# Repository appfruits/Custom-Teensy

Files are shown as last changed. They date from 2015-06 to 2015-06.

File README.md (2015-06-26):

# Custom-Teensy
This is a reference pcb and schematics for a custom Teensy 3.1 board in EAGLE CAD format. More info on this can be found in our blog post at: http://www.appfruits.com/2015/03/building-your-own-custom-teensy/

#Wiki
Please post an issue if you have trouble or questions on the design. I will add new interesting things that I found in the issues and other sources (like PJRCs official forum or from eMail conversations) to the Wiki of this project. You are kindly invited to add things, too.
https://github.com/appfruits/Custom-Teensy/wiki

## License
<br /><span xmlns:dct="http://purl.org/dc/terms/" property="dct:title">Custom Teensy 3.1</span> von <a xmlns:cc="http://creativecommons.org/ns#" href="http://www.appfruits.com/2015/03/building-your-own-custom-teensy/" property="cc:attributionName" rel="cc:attributionURL">Phillip Schuster (Appfruits)</a> ist lizenziert unter einer <a rel="license" href="http://creativecommons.org/licenses/by-sa/4.0/">Creative Commons Namensnennung - Weitergabe unter gleichen Bedingungen 4.0 International Lizenz</a>.<br />Beruht auf dem Werk unter <a xmlns:dct="http://purl.org/dc/terms/" href="https://www.pjrc.com/store/teensy31.html" rel="dct:source">https://www.pjrc.com/store/teensy31.html</a>.

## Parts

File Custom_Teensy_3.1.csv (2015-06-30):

Qty | Value | Device | Package | Parts | Description | MF | MPN | OC_FARNELL | OC_NEWARK | PROD_ID | VALUE
1 |  | LED-GREEN | LED-0603 | LED1 | LEDs | Avago | HSMG-C190
10 | 0.1uF | CAPACITOR-0.1UF | 0603-CAP | C2, C4, C5, C11, C14, C16, C18, C19, C21, C22 |  | Kemet | C0603C104J3RACTU |  |  |  | 0.1uF
1 | 1.2M | RESISTOR-1.2M | 0603-RES | R7 | Resistor | Panasonic | ERJ-3GEYJ125V |  |  |  | 1.2M
1 | 10K | RESISTOR-10K | 0603-RES | R2 | Resistor | Panasonic | ERJ-3GEYJ103V |  |  |  | 10K
1 | 10uF | CAPACITOR-10UF | 0603-CAP | C1 |  | Murata | GRM188R60J106ME47D |  |  |  | 10uF
1 | 16Mhz/8pF | CRYSTAL/SMD-5X3-GND16MHZ/8PF | CRYSTAL-SMD-5X3 | Y2 |  | ECS | ECS-160-8-30B-CKM |  |  |  | 16Mhz/8pF
1 | 1981584-1 | 1981584-1 | 1981584-1 | J1 | Receptacle, micro-USB, type A/B | Hirose | ZX62-AB-5PA(11)
1 | 1K | RESISTOR-1K | 0603-RES | R10 | Resistor | Panasonic | ERJ-3GEYJ102V |  |  |  | 1K
2 | 2.2uF | CAPACITOR-2.2UF | 0603-CAP | C17, C20 |  | Kemet | C0603C225K4PACTU |  |  |  | 2.2uF
1 | 2.2uH, 2.1A | LPS30152.2UH | LPS3015 | L1 | Shielded Power Inductor | Coilcraft | LPS3015-222MRB |  |  |  | 2.2uH, 2.1A
2 | 220K | RESISTOR-220K | 0603-RES | R4, R6 | Resistor | Panasonic | ERJ-3GEYJ224V |  |  |  | 220K
1 | 22uF | CAPACITOR-22UF | 0603-CAP | C3 |  | Murata | GRM188R60J226MEA0D |  |  |  | 22uF
1 | 2M | RESISTOR-2M | 0603-RES | R3 | Resistor | Panasonic | ERJ-3GEYJ205V |  |  |  | 2M
1 | 32.768KHz | CRYSTAL/32.768KHZ/SMD-TXC_7A | CRYSTAL-TXC-7A | Y1 |  | Epson Timing | FC-255 32.7680K-A3
1 | 33 | 2R-NEXB34V | EXB34V | RN1 | Array Chip Resistor | Panasonic | EXB-34V330JV | unknown | unknown
3 | 470 | RESISTOR-470 | 0603-RES | R9, R16, R30 | Resistor | Panasonic | ERJ-3GEYJ471V |  |  |  | 470
3 | 600 Ohm/100 Mhz | INDUCTOR-BK2125HM601-T | 0805 | L2, L3, L4 | Inductors | Taiyo Yuden | BK2125HM601-T |  |  |  | 600 Ohm/100 Mhz
1 | AMBER/ 592 nm | LED-AMBER | LED-0603 | LED | LEDs | Avago Technologies | HSMA-C190 |  |  |  | AMBER/ 592 nm
1 | MINI54TAN | MINI54TAN | MINI54TAN | U3 | MINI54TAN Bootloader from PJRC.com, preprogrammed with Teensy 3.0 bootloader.
1 | MK20DX256VLH7 | MK20DX256VLH7 | MK20DX256VLH7 | U1 |  | Freescale | MK20DX256VLH7
1 | Program | SWITCH-MOMENTARY-2-SMD-1101NE | TACTILE-SWITCH-1101NE | PROGRAM | Various NO switches- pushbuttons, reed, etc | C&K Components | RS-282G05A3-SM RT
1 | TPS61200 | TPS61200 | QFN-10_PAD | U2 | DC to DC Booster | Texas Instruments | TPS61200DRCR |  |  | IC-10035

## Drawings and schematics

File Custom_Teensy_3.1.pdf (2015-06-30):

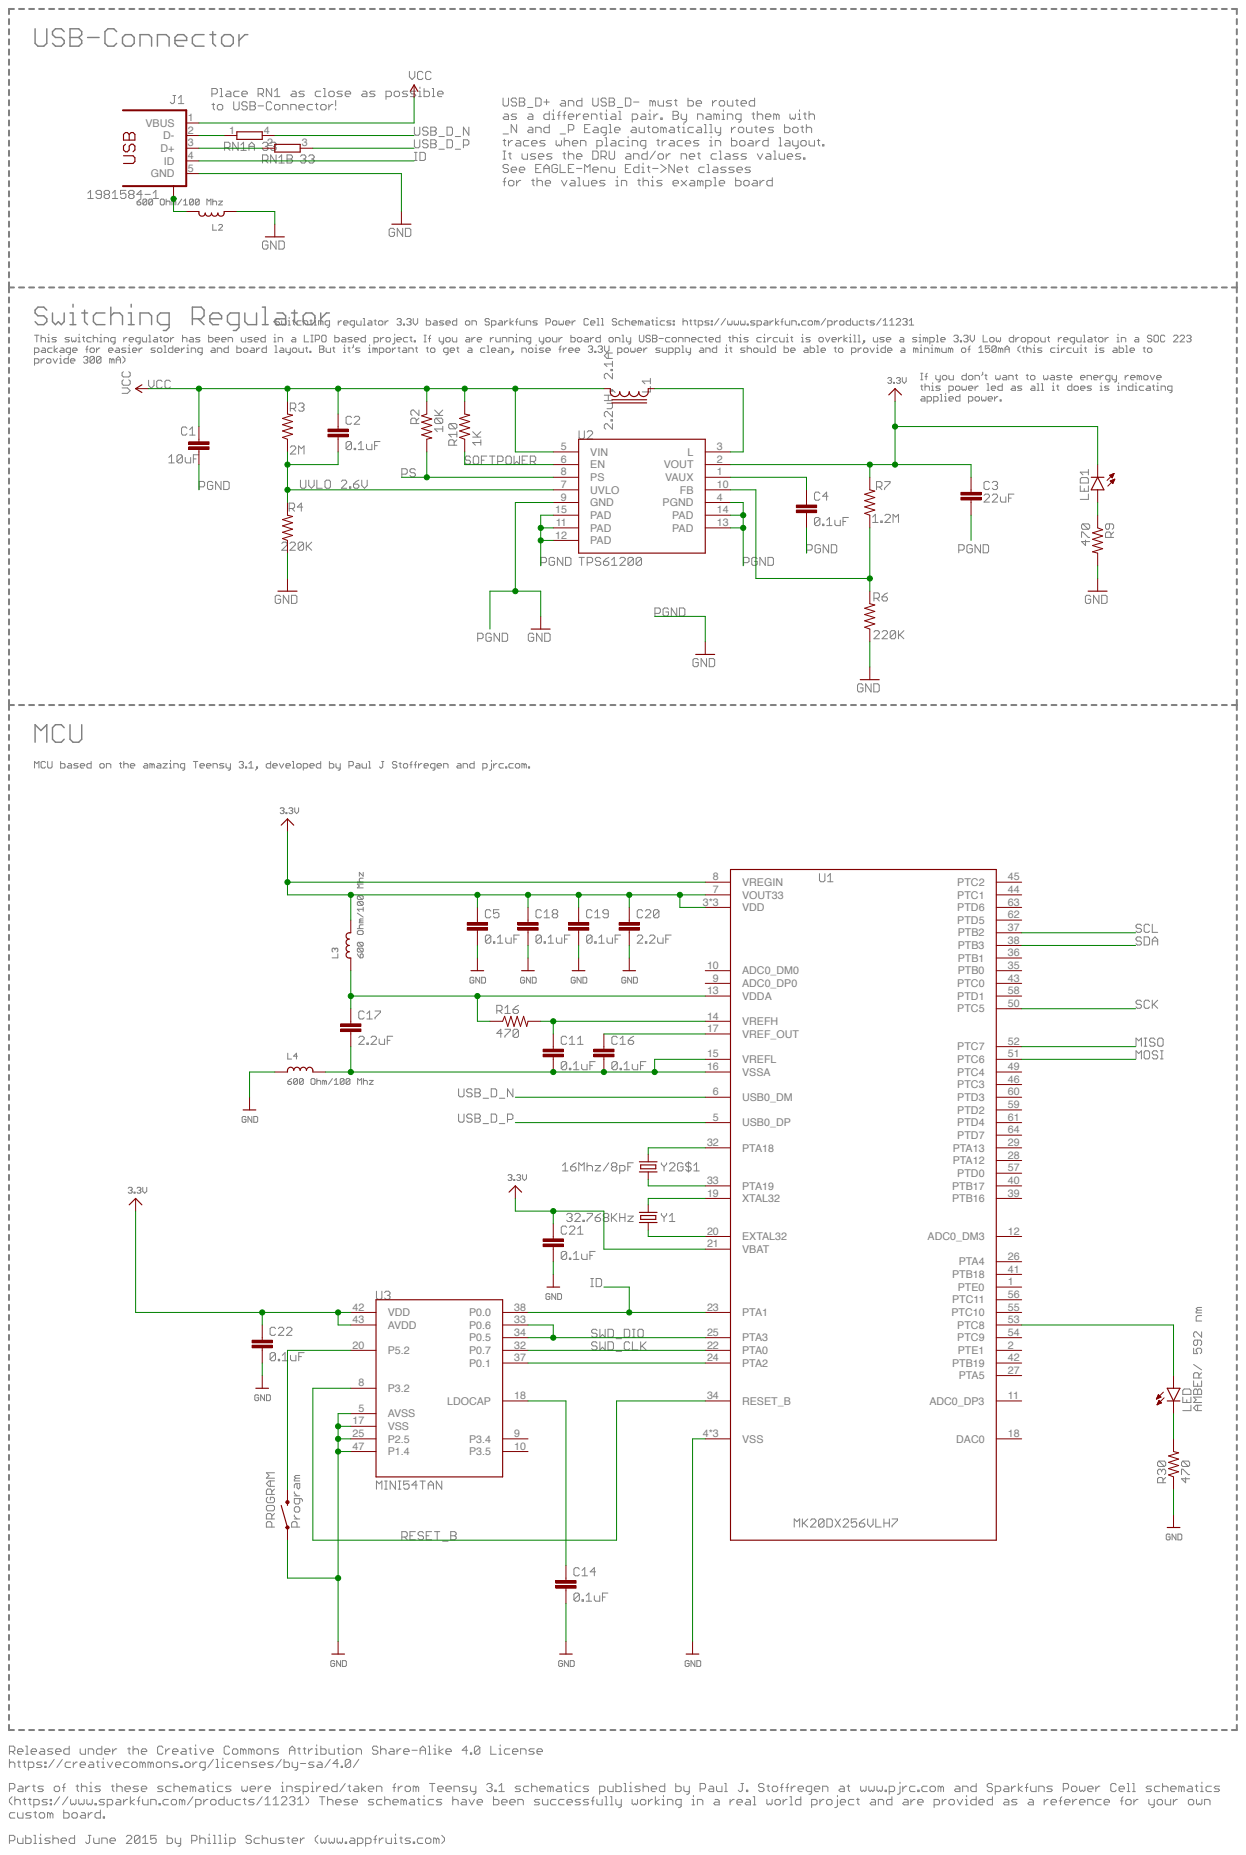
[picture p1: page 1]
GND; PAD 15 PAD 11; PAD 12; PAD; 13 PAD; 14 PGND; UVLO; VAUX; VIN; VOUT; VDD 42; VSS 17; AVDD 43; AVSS; LDOCAP; VREGIN; VOUT33; 7 VDD 3*3; ADC0_DM0 10; ADC0_DP0; 9 VDDA 13; VREFH 14 VREF_OUT 17; VREFL 15 VSSA 16; USB0_DM; USB0_DP; PTA18 32; PTC2; PTC1; PTD6; PTD5; PTB2; PTB3; PTB1; PTB0; PTD1; 58 PTC0; PTC5; PTC7; PTC6; PTC4; PTC3; PTD3; PTD2; PTD4; PTD7; PTA13; PTA12; PTD0; PTB17; PTB16; ADC0_DM3; PTA4; PTB18; PTE0; PTC11; PTC10; PTC8; PTC9; PTE1; PTB19; PTA5; ADC0_DP3; PTA19 33 XTAL32 19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

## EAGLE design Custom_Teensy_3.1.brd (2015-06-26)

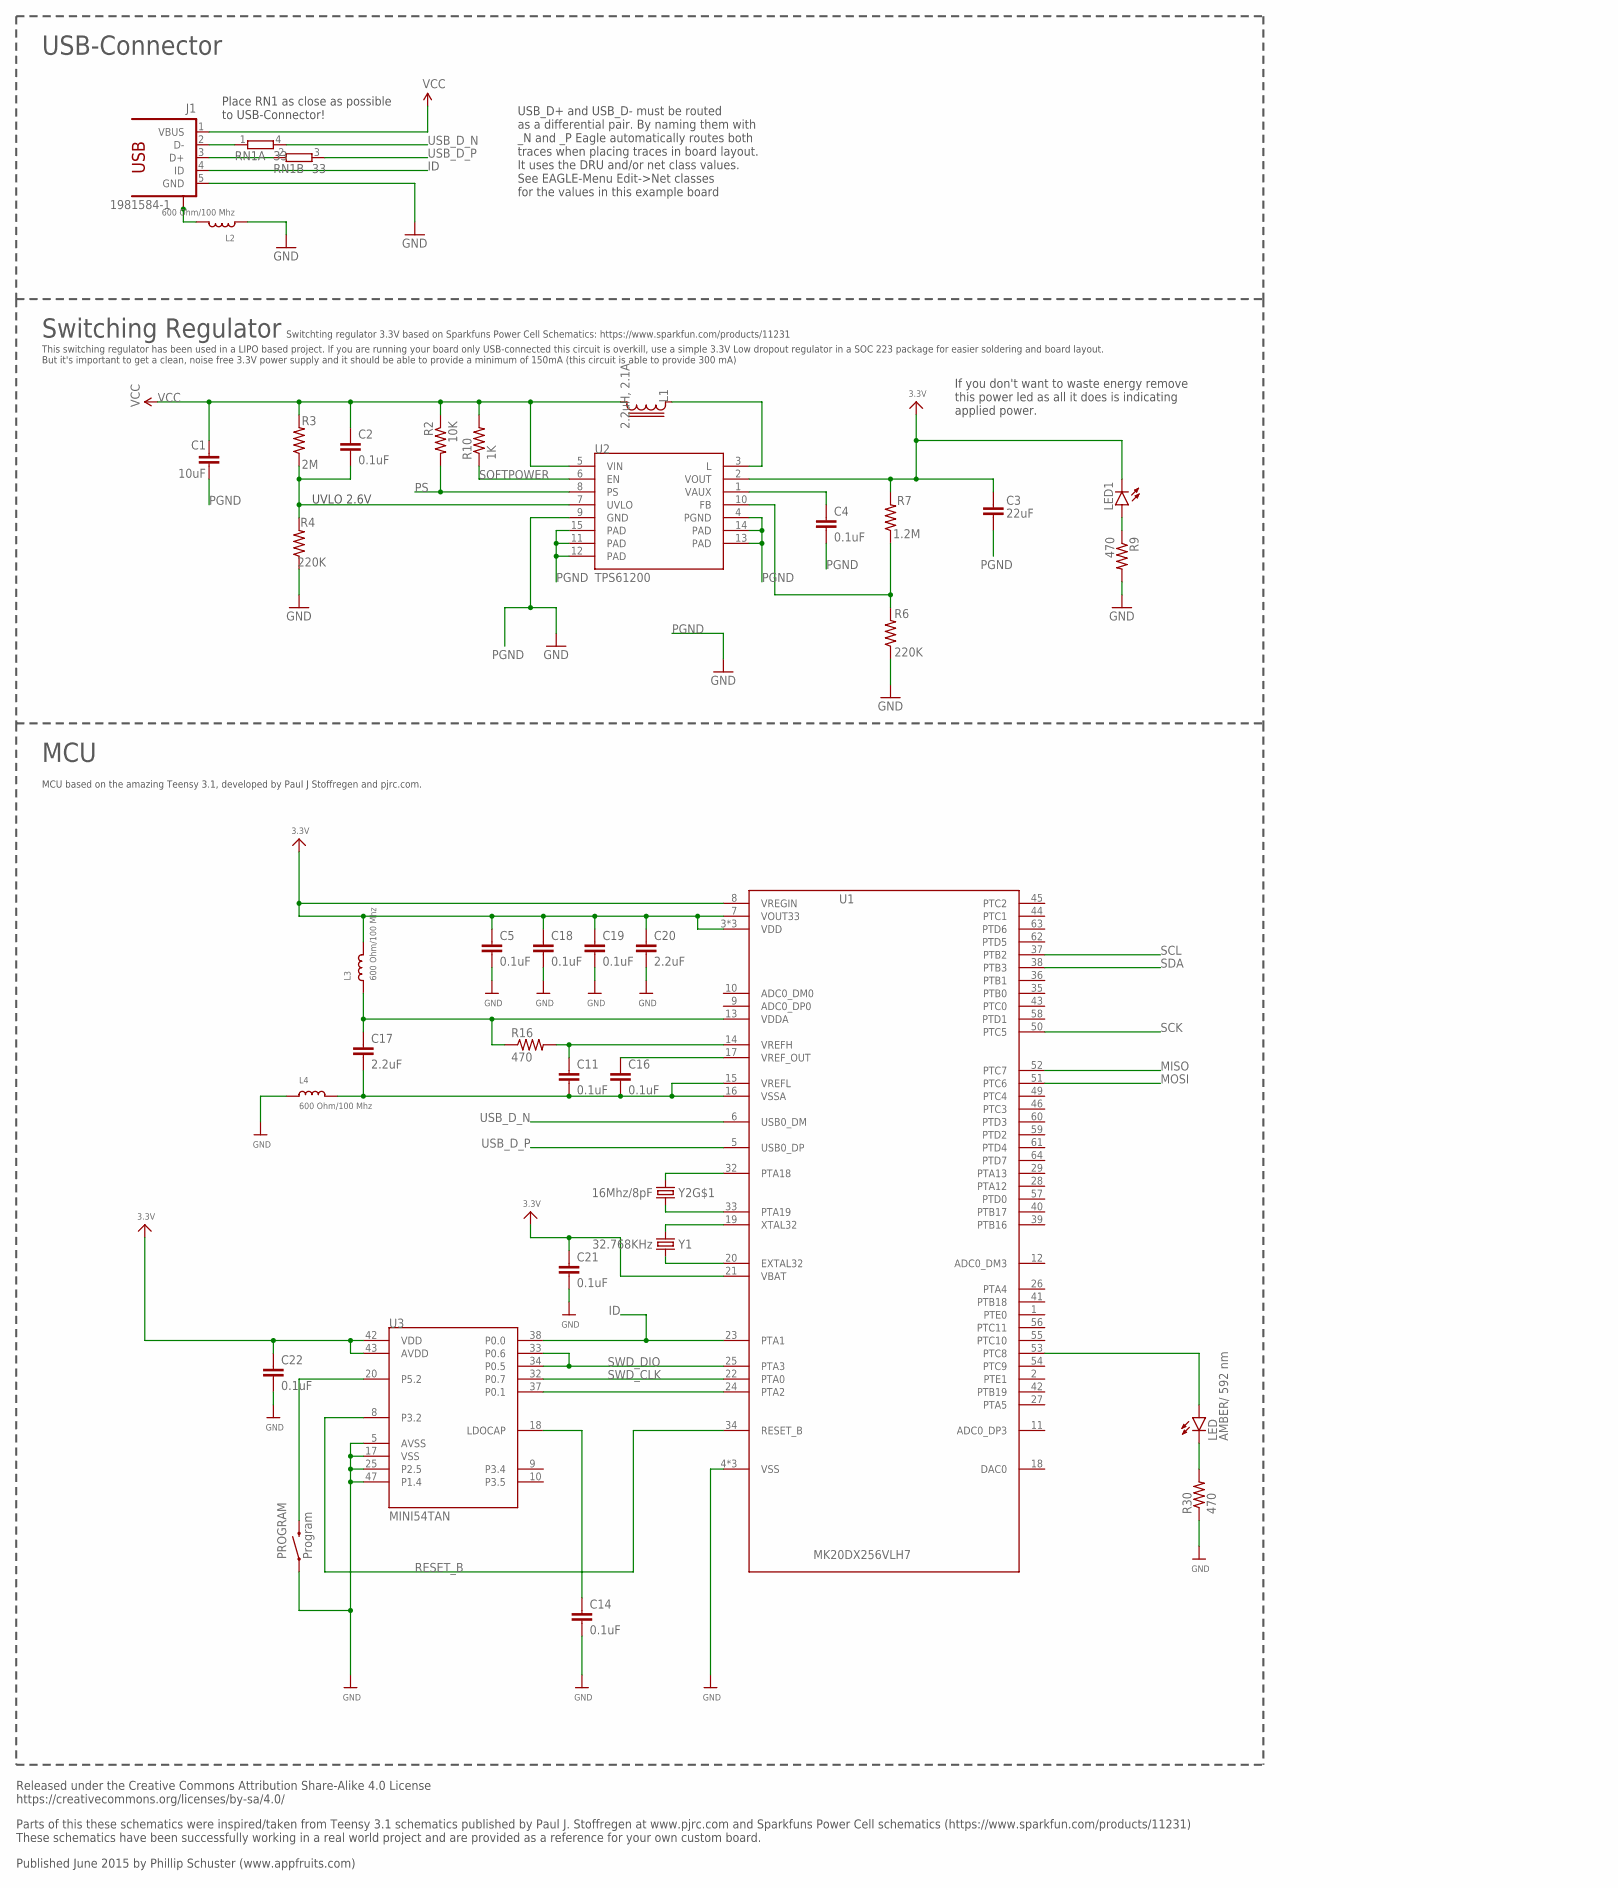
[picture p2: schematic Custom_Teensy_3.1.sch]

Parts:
C1: 10uF; 0603-CAP
C2, C4, C5, C11, C14, C16, C18, C19, C21, C22: 0.1uF; 0603-CAP
C3: 22uF; 0603-CAP
C17, C20: 2.2uF; 0603-CAP
J1: 1981584-1; MPN ZX62-AB-5PA(11)
L1: 2.2uH, 2.1A; LPS3015
L2, L3, L4: 600 Ohm/100 Mhz; 0805
LED: AMBER/ 592 nm; LED-0603
LED1: LED-GREEN; LED-0603
PROGRAM: Program; TACTILE-SWITCH-1101NE; MPN RS-282G05A3-SM RT
R2: 10K; 0603-RES
R3: 2M; 0603-RES
R4, R6: 220K; 0603-RES
R7: 1.2M; 0603-RES
R9, R16, R30: 470; 0603-RES
R10: 1K; 0603-RES
RN1: 33; EXB34V; MPN EXB-34V330JV
U1: MK20DX256VLH7; MPN MK20DX256VLH7
U2: TPS61200; QFN-10_PAD
U3: MINI54TAN
Y1: 32.768KHz; CRYSTAL-TXC-7A; MPN FC-255 32.7680K-A3
Y2: 16Mhz/8pF; CRYSTAL-SMD-5X3; MPN ECS-160-8-30B-CKM

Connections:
3.3V: C3.1, C5.1, C18.1, C19.1, C20.1, C21.1, C22.1, L3.2, LED1.C, R7.2, U1.3 (VDD), U1.7 (VOUT33), U1.8 (VREGIN), U1.21 (VBAT), U1.30 (VDD), U1.48 (VDD), U2.2 (VOUT), U3.42 (VDD), U3.43 (AVDD)
FB: R6.2, R7.1, U2.10 (FB)
GND: C5.2, C14.2, C18.2, C19.2, C20.2, C21.2, C22.2, J1.5 (GND), L2.1, L4.1, PROGRAM.P$1 (1), R4.1, R6.1, R9.2, R30.1, U1.4 (VSS), U1.31 (VSS), U1.47 (VSS), U3.5 (AVSS), U3.17 (VSS), U3.25 (P2.5), U3.47 (P1.4)
ID: J1.4 (ID), U1.23 (PTA1), U3.38 (P0.0)
MISO: U1.52 (PTC7)
MOSI: U1.51 (PTC6)
unnamed: LED1.A, R9.1
unnamed: L1.1, U2.3 (L)
unnamed: LED.A, U1.53 (PTC8)
unnamed: U1.24 (PTA2), U3.37 (P0.1)
unnamed: LED.C, R30.2
unnamed: PROGRAM.P$2 (2), U3.20 (P5.2)
unnamed: C14.1, U3.18 (LDOCAP)
unnamed: U1.32 (PTA18), Y2.3 (2)
unnamed: U1.33 (PTA19), Y2.1
unnamed: U1.19 (XTAL32), Y1.P$2 (2)
unnamed: U1.20 (EXTAL32), Y1.P$1 (1)
PGND: C1.2, C3.2, C4.2, U2.4 (PGND), U2.9 (GND), U2.11 (PAD), U2.12 (PAD), U2.13 (PAD), U2.14 (PAD), U2.15 (PAD)
PS: R2.2, U2.8 (PS)
RESET_B: U1.34 (RESET_B), U3.8 (P3.2)
SCK: U1.50 (PTC5)
SCL: U1.37 (PTB2)
SDA: U1.38 (PTB3)
SOFTPOWER: R10.1, U2.6 (EN)
SWD_CLK: U1.22 (PTA0), U3.32 (P0.7)
SWD_DIO: U1.25 (PTA3), U3.33 (P0.6), U3.34 (P0.5)
USB_CON_N: J1.2 (D-), RN1.1
USB_CON_P: J1.3 (D+), RN1.2 (1)
USB_D_N: RN1.4 (2), U1.6 (USB0_DM)
USB_D_P: RN1.3 (2), U1.5 (USB0_DP)
USB_SHIELD: J1.S1, J1.S2, J1.S3, J1.S4, L2.2
UVLO: C2.2, R3.1, R4.2, U2.7 (UVLO)
VAUX: C4.1, U2.1 (VAUX)
VCC: C1.1, C2.1, J1.1 (VBUS), L1.2, R2.1, R3.2, R10.2, U2.5 (VIN)
VDDA: C17.1, L3.1, R16.1, U1.13 (VDDA)
VREFH: C11.1, R16.2, U1.14 (VREFH)
VREFL: C11.2, C16.2, C17.2, L4.2, U1.15 (VREFL), U1.16 (VSSA)
VREF_OUT: C16.1, U1.17 (VREF_OUT)

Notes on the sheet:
UVLO 2.6V
USB-Connector
Switching Regulator
MCU
MCU based on the amazing Teensy 3.1, developed by Paul J Stoffregen and pjrc.com.
Place RN1 as close as possible to USB-Connector!
If you don't want to waste energy remove this power led as all it does is indicating applied power.
USB_D+ and USB_D- must be routed as a differential pair. By naming them with _N and _P Eagle automatically routes both traces when placing traces in board layout. It uses the DRU and/or net class values. See EAGLE-Menu Edit->Net classes for the values in this example board
Released under the Creative Commons Attribution Share-Alike 4.0 License https://creativecommons.org/licenses/by-sa/4.0/
Parts of this these schematics were inspired/taken from Teensy 3.1 schematics published by Paul J. Stoffregen at www.pjrc.com and Sparkfuns Power Cell schematics (https://www.sparkfun.com/products/11231) These schematics have been successfully working in a real world project and are provided as a r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
Published June 2015 by Phillip Schuster (www.appfruits.com)
Switchting regulator 3.3V based on Sparkfuns Power Cell Schematics: https://www.sparkfun.com/products/11231
This switching regulator has been used in a LIPO based project. If you are running your board only USB-connected this circuit is overkill, use a simple 3.3V Low dropout regulator in a SOC 223 package for easier soldering and board layout. But it's important to get a clean, noise free 3.3V power sup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

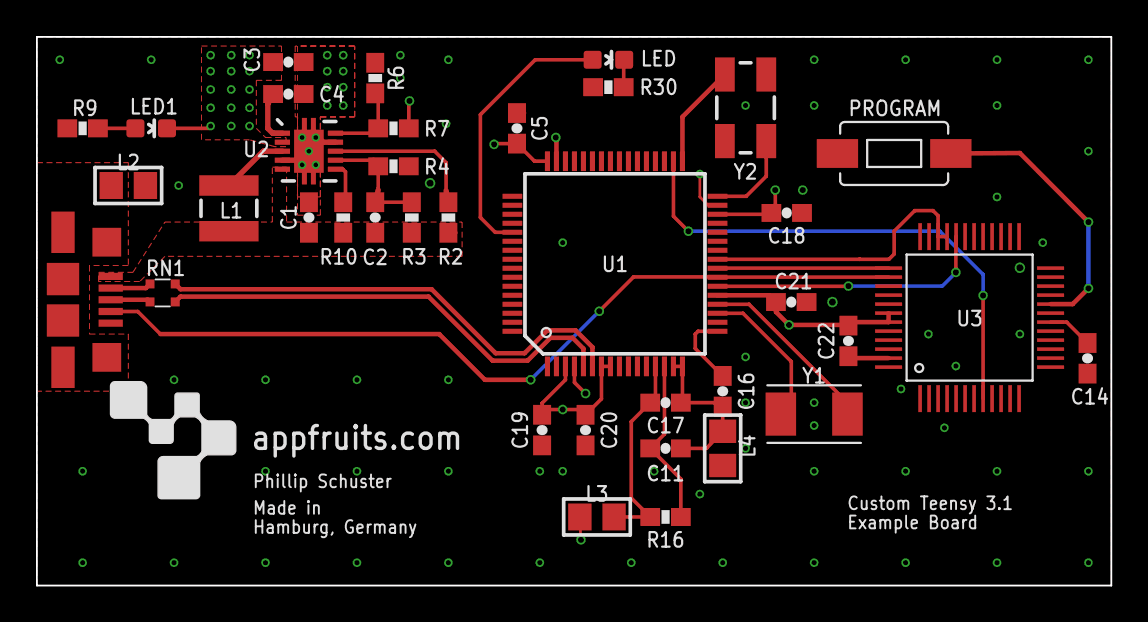
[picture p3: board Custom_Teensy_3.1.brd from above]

Board: 4 copper layers, 59.7 x 30.5 mm, 37 parts (0 on the bottom side), 33 nets.

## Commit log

2015-06-26 Added board and schematics
    [Custom_Teensy_3.1.brd, Custom_Teensy_3.1.sch]
2015-06-26 Removed the I2C connection between MINI54TAN and MK20 as these are not used
    As this connection is shown in the official Teensy 3.1 schematics I
    have also added it. Paul today stated in the official PJRC forum that
    this connection is not used and will never be used. So I removed it.
    [Custom_Teensy_3.1.brd, Custom_Teensy_3.1.sch]
2015-06-30 Added PDF for schematics and BOM for those that do not use EAGLE CAD
    [Custom_Teensy_3.1.csv]

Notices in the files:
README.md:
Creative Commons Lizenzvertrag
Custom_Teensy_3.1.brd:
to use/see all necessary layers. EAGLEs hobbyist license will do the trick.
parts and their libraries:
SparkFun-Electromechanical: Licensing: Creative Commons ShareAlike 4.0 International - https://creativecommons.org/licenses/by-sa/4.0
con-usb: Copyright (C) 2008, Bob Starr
